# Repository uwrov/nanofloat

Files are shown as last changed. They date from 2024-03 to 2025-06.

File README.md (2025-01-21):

# NanoFloat

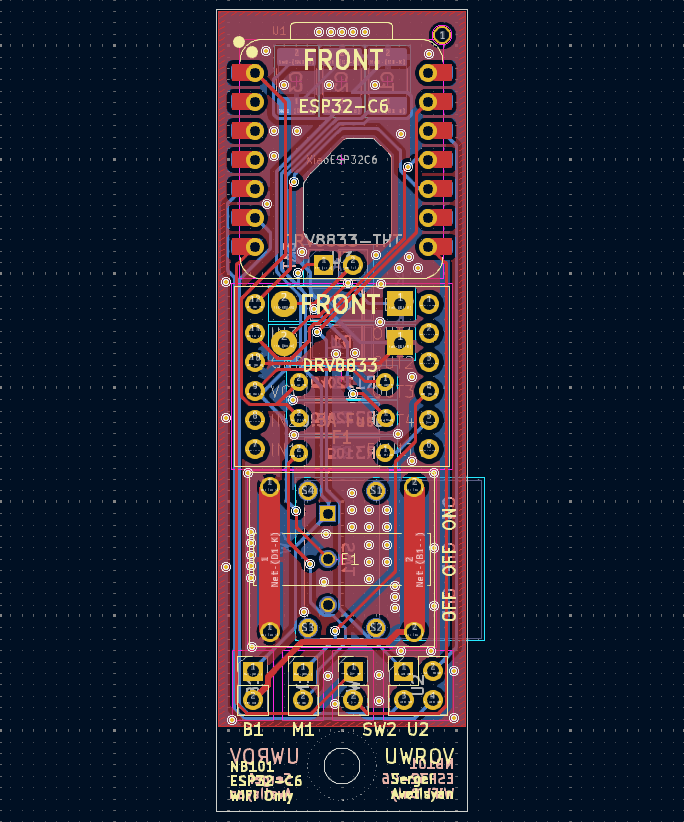
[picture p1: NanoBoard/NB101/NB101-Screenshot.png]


# Helpful Links:
>[Micropython Docs](https://docs.micropython.org/en/latest/esp32/quickref.html)

>[WebREPL GitHub](https://github.com/micropython/webrepl)

>[Seeed Studio ESP32C6 (Latest Version) Pinout](https://wiki.seeedstudio.com/xiao_esp32c6_getting_started/)

>[Seeed Studio ESP32C3 Pinout](https://wiki.seeedstudio.com/xiao_esp32c6_getting_started/)

>[DRV-8833 Motor Driver Pinout and User Guide](https://lastminuteengineers.com/drv8833-arduino-tutorial/)

>[Blue Robotics Pressure Sensor](https://bluerobotics.com/store/sensors-cameras/sensors/bar02-sensor-r1-rp/)

>[Flashing Micropython Firmware Reference Guide](https://docs.micropython.org/en/latest/esp32/tutorial/intro.html#esp32-intro)

>[MS583730BA01-50 Pressure Sensor Datasheet](https://www.te.com/usa-en/product-MS583730BA01-50.datasheet.pdf)

>[MS5837 Official Python Library](https://github.com/bluerobotics/ms5837-python)

>[Standalone Pressure Sensor DigiKey Page](https://www.digikey.com/en/products/detail/te-connectivity-measurement-specialties/MS583730BA01-50/5629501)

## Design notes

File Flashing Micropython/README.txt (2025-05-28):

ESP32C3:

1. Hold down B or Boot button and connect the board to your PC using a data USB-C cable (this will put it in bootloader mode).

2. Open CMD

3. devmgmt.msc and check COM port

4. esptool --port COM_ erase_flash

5. If you cloned the repo, cd to this directory of the directory where you downloaded your flash binary

6. esptool --port COM_ write_flash -z 0x0 ESP32C6-MicroPython.bin

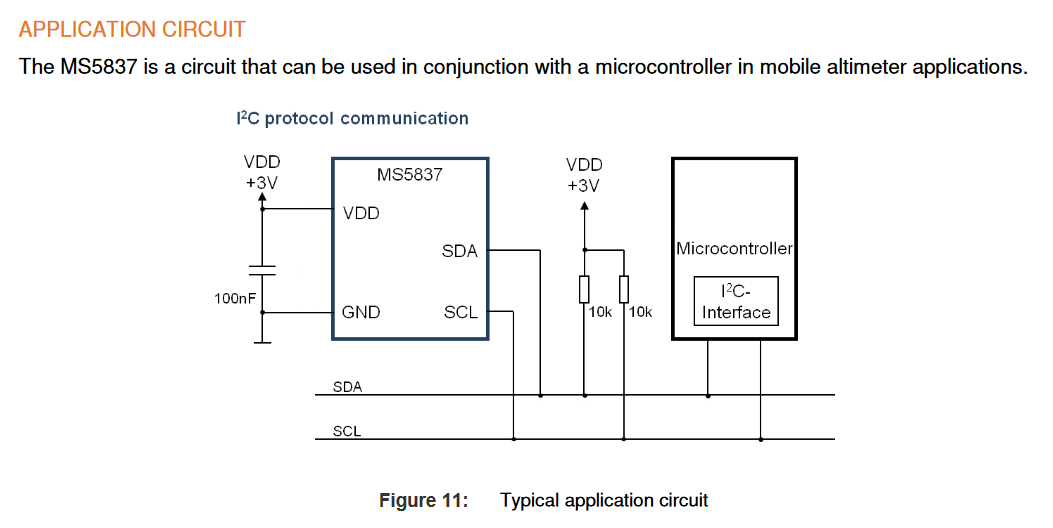
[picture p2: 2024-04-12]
Schematic-Image.png

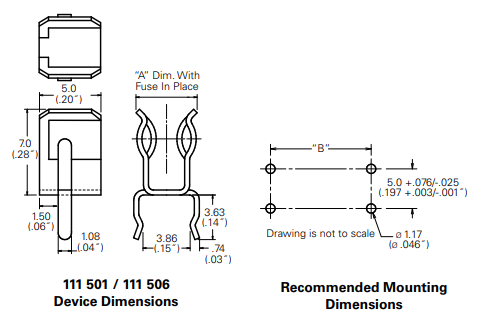
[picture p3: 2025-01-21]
FuseHolderDimensions.png

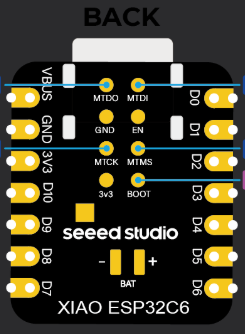
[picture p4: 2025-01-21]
ESP32C6-Reference-Backside.png

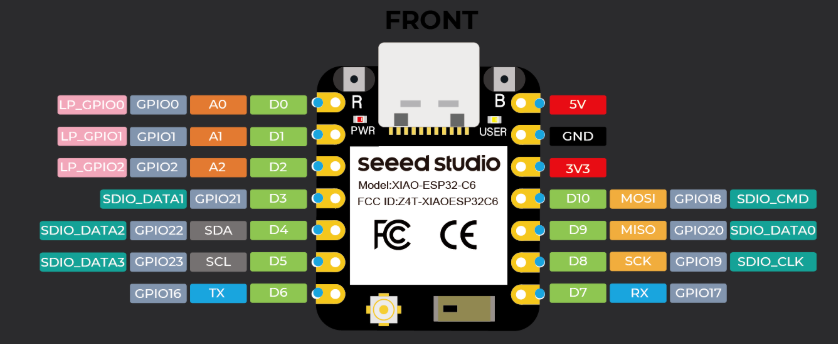
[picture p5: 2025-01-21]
ESP32C6-Reference.png

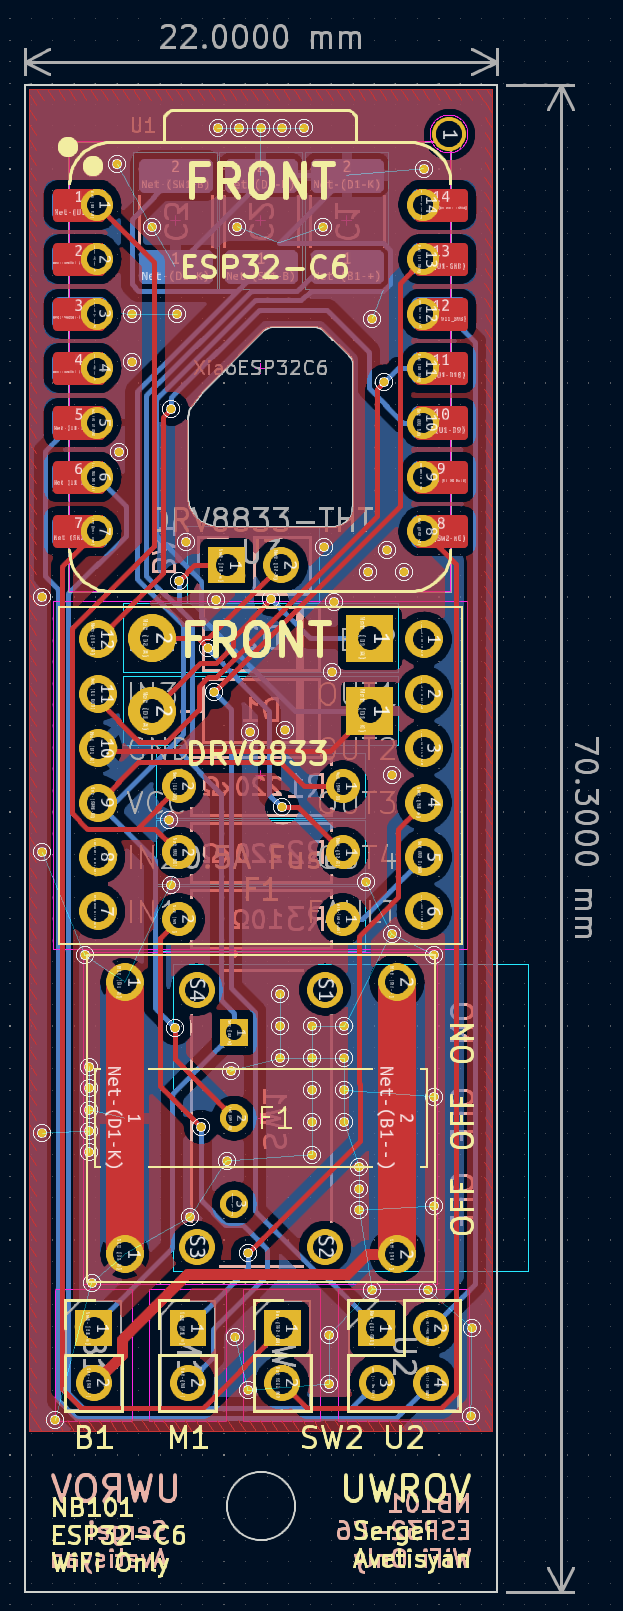
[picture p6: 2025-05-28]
NanoBoard/NB101/NB101.png

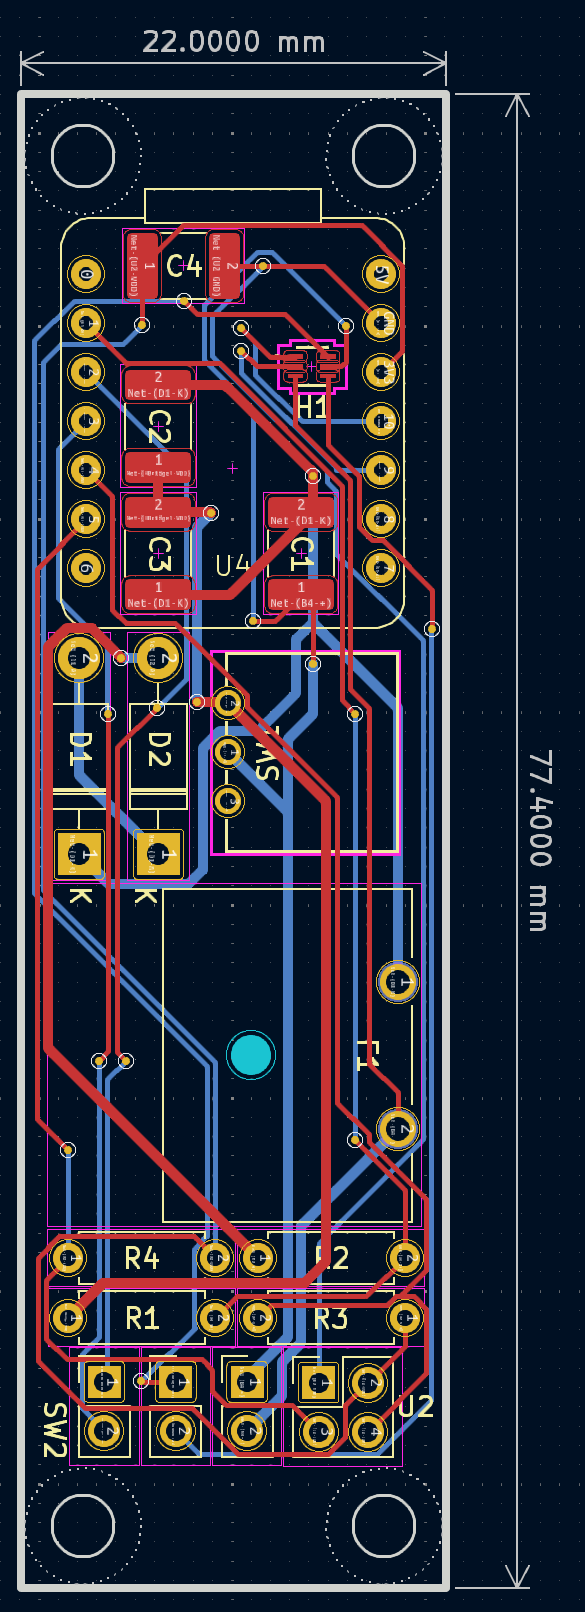
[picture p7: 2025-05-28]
NanoBoard/NB001/NB001.png

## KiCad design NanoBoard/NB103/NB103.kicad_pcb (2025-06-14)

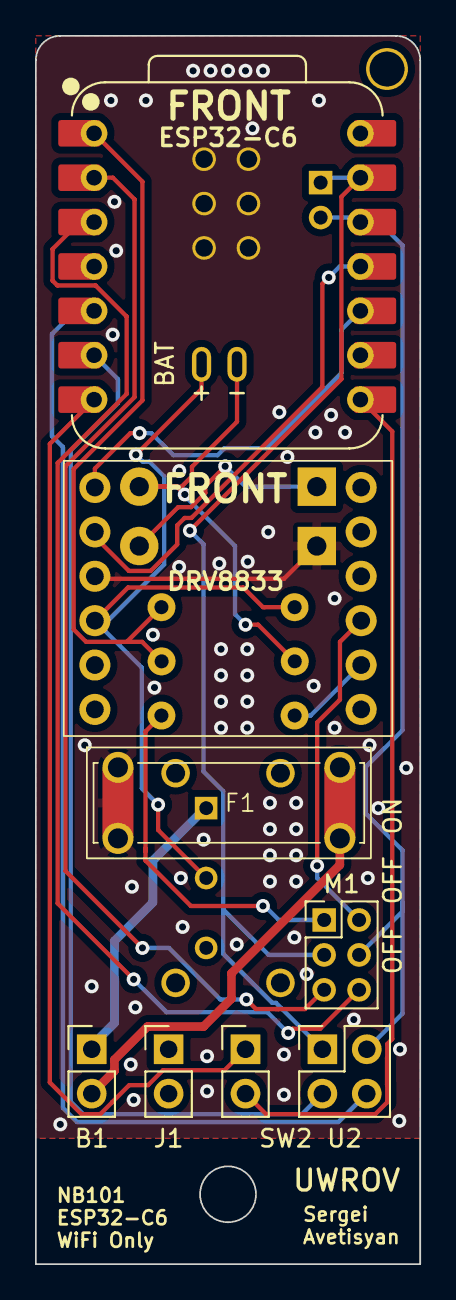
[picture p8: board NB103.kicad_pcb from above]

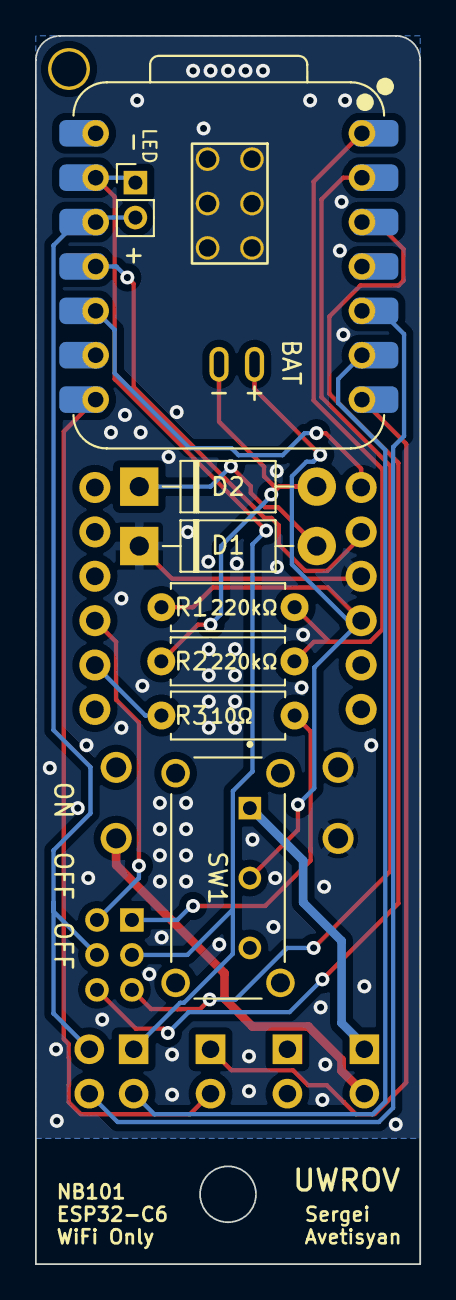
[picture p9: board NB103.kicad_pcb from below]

Board: 2 copper layers, 22.0 x 70.3 mm, 17 parts (8 on the bottom side), 18 nets.

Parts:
B1: 6V; PinHeader_1x02_P2.54mm_Vertical
BAT: PinHeader_1x02_P2.54mm_Vertical
D1, D2: Rectifier Diode; D_DO-41_SOD81_P10.16mm_Horizontal
F1: 0.5A Fuse; Fuse-Holder-01110501Z
J1: Motor_DC; PinHeader_1x02_P2.54mm_Vertical
LED: PinHeader_1x02_P2.00mm_Vertical
M1, M1#2: PinHeader_2x03_P2.00mm_Vertical
R1, R2: 220kOhm; R_Axial_DIN0207_L6.3mm_D2.5mm_P7.62mm_Horizontal
R3: 10 Ohm; R_Axial_DIN0207_L6.3mm_D2.5mm_P7.62mm_Horizontal
SW1: SW; Slide-Switch-EG1224
SW2: Limit Switch; PinHeader_1x02_P2.54mm_Vertical
U1: XiaoESP32C6; XIAO-ESP32C6-DIP
U2: MS583730BA01-50; PinHeader_2x02_P2.54mm_Vertical
U3: DRV8833-THT

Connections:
unnamed: B1.1 (+), SW1.1 (A)
unnamed: B1.2 (-), F1.2
unnamed: D1.2 (A), D2.1 (K)
unnamed: D1.1 (K), F1.1, U3.10 (GND)
unnamed: BAT.2, D2.2 (A), R2.1
unnamed: M1#2.2, U3.4 (Out3)
unnamed: M1#2.1, R3.2
unnamed: BAT.1, R1.1, SW1.2 (B), U3.9 (VCC)
unnamed: SW2.1 (COM), U1.7 (D6)
unnamed: SW2.2 (NC), U1.8 (D7)
unnamed: R1.2, R2.2, U1.1 (D0)
unnamed: U1.5 (D4_SDA), U2.4 (SDA)
unnamed: U1.6 (D5_SCL), U2.3 (SCL)
unnamed: U1.10 (D9), U3.12 (In4)
unnamed: U1.11 (D10), U3.11 (In3)
unnamed: LED.1, M1#2.3, U1.13 (GND), U2.1 (GND)
unnamed: LED.2, M1#2.4, U1.12 (VCC_3V3), U2.2 (VDD)
unnamed: R3.1, U3.5 (Out4)

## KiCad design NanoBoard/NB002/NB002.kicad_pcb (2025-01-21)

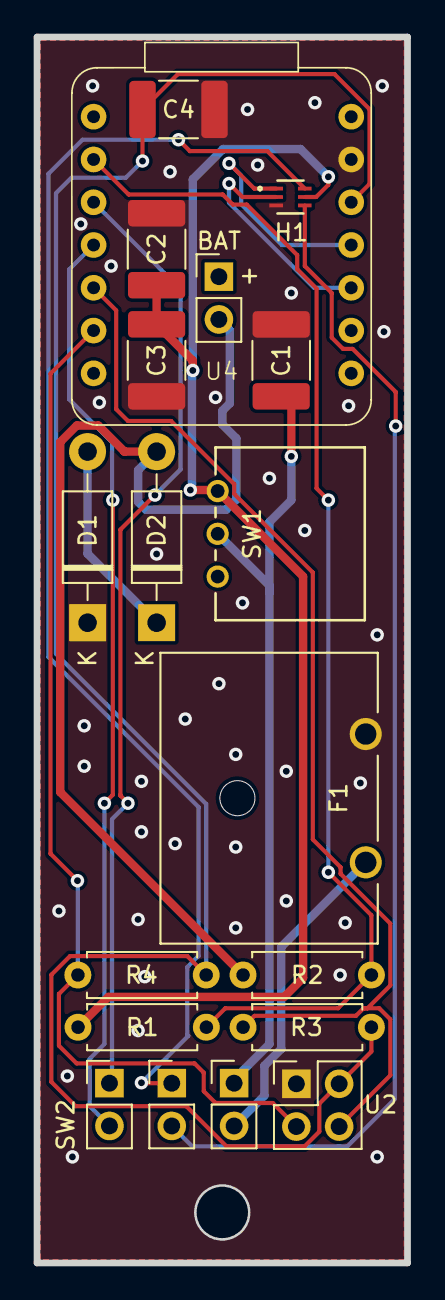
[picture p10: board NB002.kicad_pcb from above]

Board: 2 copper layers, 22.0 x 72.8 mm, 19 parts (0 on the bottom side), 13 nets.

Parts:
B4: 1.5V; PinHeader_1x02_P2.54mm_Vertical
BAT: PinHeader_1x02_P2.54mm_Vertical
C1, C2, C3, C4: C_Small; C_1812_4532Metric_Pad1.57x3.40mm_HandSolder
D1, D2: Rectifier Diode; D_DO-41_SOD81_P10.16mm_Horizontal
F1: 2A Fuse; FUSE_01530007Z
H1: DRV8220DRLR
M1: Motor_DC; PinHeader_1x02_P2.54mm_Vertical
R1, R2: 220kOhm; R_Axial_DIN0207_L6.3mm_D2.5mm_P7.62mm_Horizontal
R3, R4: 10kOhm; R_Axial_DIN0207_L6.3mm_D2.5mm_P7.62mm_Horizontal
SW1: SW; SW_09.10290.01_EAO
SW2: Limit Switch; PinHeader_1x02_P2.54mm_Vertical
U2: MS583730BA01-50; PinHeader_2x02_P2.54mm_Vertical
U4: XiaoESP32C3; XIAO_ESP32C3_THT

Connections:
unnamed: B4.1 (+), C1.1, SW1.1 (A)
unnamed: B4.2 (-), F1.2
unnamed: D1.2 (A), D2.1 (K)
unnamed: C1.2, C2.2, C3.1, C4.2, D1.1 (K), F1.1, H1.3, U2.1 (GND), U4.GND
unnamed: BAT.2, D2.2 (A), R2.1
unnamed: H1.1, U4.10 (D9)
unnamed: H1.6, M1.1 (+)
unnamed: H1.4, M1.2 (-)
unnamed: C2.1, C3.2, H1.5, R1.1, SW1.2 (B)
unnamed: R4.1, U2.3 (SCL), U4.5 (D4_SDA)
unnamed: R3.2, U2.4 (SDA), U4.4 (D3)
unnamed: C4.1, R3.1, R4.2, U2.2 (VDD), U4.3V3
unnamed: R1.2, R2.2, U4.1 (D0)

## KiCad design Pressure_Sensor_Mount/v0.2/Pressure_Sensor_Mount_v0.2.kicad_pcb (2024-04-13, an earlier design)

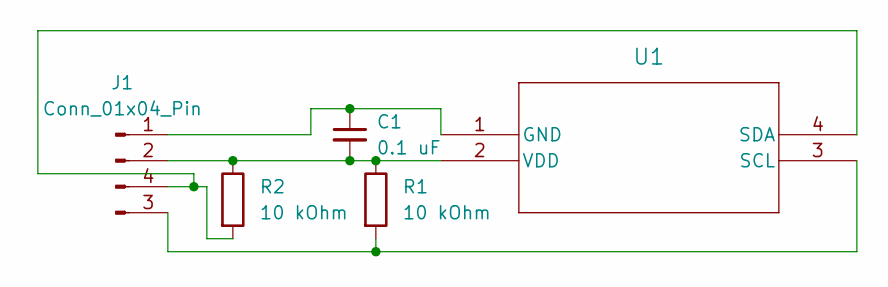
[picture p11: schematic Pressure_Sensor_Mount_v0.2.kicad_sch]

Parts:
C1: 0.1 uF; C_Disc_D3.0mm_W1.6mm_P2.50mm
J1: Conn_01x04_Pin; PinHeader_1x04_P2.54mm_Vertical
R1, R2: 10 kOhm; R_Axial_DIN0309_L9.0mm_D3.2mm_P12.70mm_Horizontal
U1: Pressure Sensor Footprint

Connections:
unnamed: C1.1, J1.1, U1.1 (GND)
unnamed: C1.2, J1.2, R1.1, R2.1, U1.2 (VDD)
unnamed: J1.3, R1.2, U1.3 (SCL)
unnamed: J1.4, R2.2, U1.4 (SDA)

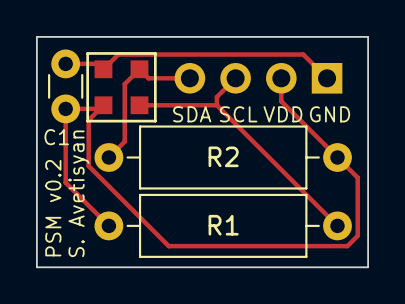
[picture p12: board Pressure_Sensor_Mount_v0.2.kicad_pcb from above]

Board: 2 copper layers, 18.4 x 12.8 mm, 5 parts (1 on the bottom side), 4 nets.

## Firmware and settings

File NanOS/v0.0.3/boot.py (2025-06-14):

#================================================================================================================================================
#                                                              imports

# This file is executed on every boot (including wake-boot from deepsleep)
# It includes the entire code for the nanofloat, all functions are defined here

# Importing sleep to allow for waiting
from time import sleep, sleep_ms

# Importing Piston Position
# Reference save_position function to see how the position is updated.
import piston_pos
position = piston_pos.position

# Impoting sys, it is used in the sys.exit() function within endFunc()
import sys

# Importing the WiFi config files, which store the network name, or SSID, and the password
import wlan_cfg

# Importing the i2c library for our pressure sensor
#import ms5837

# Importing the following from the esp32's operating system:
#       - Pin to control GPIOs
#       - I2C to control sensors operating over the i2c serial bus
from machine import Pin, I2C, ADC

# Importing WebREPL to interface wirelessly with the controller's WiFi Access Point 
import webrepl

# Importing network which will allow the controller to start up its own WiFi Access Point
import network 

# Starting up the WiFi Access Point. In this case, the network is set to AP_IF, putting it into access point mode.
# In other use cases, the network may be set to STA_IF which sets it as a default station which can connect to WiFi.
try:
    ap = network.WLAN(network.STA_IF)
    ap.config(beep)
    print("Startup in Station Mode")
except:
    print("---")
    print("WARNING: ROUTER CONNECTION FAILED: Initializing Access-Point Mode")
    print("---")
    try:
        ap = network.WLAN(network.AP_IF)
        ap.config(ssid = wlan_cfg.network_name, max_clients = 1)
        ap.active(True)
        print("Startup in Access-Point Mode Successful")
    except:
        print("Startup in Access-Point Mode Failed, USB Connection Required")

# Starting up WebREPL access, which sets the password for access and assigns the default IP address to the controller
# Reset the psasword to what you prefer by changing it in the webrepl_cfg.py file, default is "123"
webrepl.start()

# Defining the GPIOs (digital pin numbers do not always align with true GPIO numbers, check Seeed Studio XIAO ESP32C3 datasheet)
d1 = Pin(1, Pin.IN) #------------------ Encoder A phase
d2 = Pin(2, Pin.IN) #------------------ Encoder B phase
d3 = Pin(21, Pin.OUT) #---------------- UNUSED
d4 = Pin(22) #------------------------- I2C bus SDA
d5 = Pin(23) #------------------------- I2C bus SCL
d6 = Pin(16, Pin.IN, Pin.PULL_DOWN) #-- Limit Switch input pin
d7 = Pin(17, Pin.OUT) #---------------- Limit Switch Pullup pin (Enable/Disable limit switch)
d8 = Pin(19, Pin.OUT) #---------------- UNUSED
d9 = Pin(20, Pin.OUT) #---------------- Motor Input 1
d10 = Pin(18, Pin.OUT) #--------------- Motor Input 2

# Defining the encoder read pins
en_A = d1
en_B = d2

# Defining the pins for the I2C bus and creating the i2c object
sda = d4
scl = d5
i2c = I2C(scl=scl, sda=sda)

# Defining the Limit Switch Pins and setting the limit switch activator pin to be pulled high, or enabled.
lim_sw_state = d6
lim_sw_activate = d7
lim_sw_activate.value(1)

# Defining the Motor Input Pins
motor1 = d9
motor2 = d10

#================================================================================================================================================
#                                                           piston_out

def piston_out():
    motor1.value(1)
    motor2.value(0)

#================================================================================================================================================
#                                                           piston_in

def piston_in():
    motor1.value(0)
    motor2.value(1)

#================================================================================================================================================
#                                                           piston_stop

def piston_stop():
    motor1.value(0)
    motor2.value(0)

#================================================================================================================================================
#                                                           save_position

def save_position():
    
    global position
    
    with open("piston_pos.py", "w") as f:

        f.write('position = %d' % (position))
        
        f.close()
        
#================================================================================================================================================
#                                                           position_reset

def position_reset():
    
    global position
    
    position = 0
    
    save_position()

#================================================================================================================================================
#                                                           piston_move

# piston_move() requires three arguments: method, target, and units (optional, raw counts assumed).
#
# method: a string which decides whether the piston should move an arbitrary delta_x or if it should move to a specified position.
# |
# '--> accepts: "rel" or "relative"
#               "abs" or "absolute"
#
# target: a float representing either the relative distance the piston should move or the absolute position to which it should move.
# |
# '--> accepts: for relative values, either positive or negative floats for retraction and extension respectively
#               for absolute values, only positive floats
#
# units: a string which defines the units of the target argument. If left unspecified, raw counts are used. (WORK IN PROGRESS, CURRENTLY SUPPRESSED)
# |
# '--> accepts: "cm" (centimeters)
#               "mm" (millimeters)
#               "revs_o" (revolutions of output shaft)
#               "revs_i" (revolutions of input shaft)

# A-Channel previous state tracker initialization
a_prev = 0

delta = 0

# Encoder ISR to run as the handler for the interrupt and update position
def encoder_isr(pin):
    global delta, a_prev
    a = en_A.value()
    if a != a_prev:
        delta += 1

# Initializing interrupt to watch the encoder outputs
en_A.irq(trigger=Pin.IRQ_RISING, handler=encoder_isr)

target_pos = position
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

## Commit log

2024-03-08 Prototype Pressure Sensor Mounting PCB
    [nanofloat-pressure-sensor-mount.kicad_pcb]
2024-03-08 uploading NanOS v0.0.1
    v0.0.1, as demonstrated on 3/3/2024. The first functional prototype of NanOS.
2024-03-08 uploaded NanOS v0.0.1
    NanOS v0.0.1 as demonstrated on 3/3/24. The first functional prototype, many features missing but main structure is defined.
    [boot.py]
2024-03-11 Updating KiCAD project files
    [nanofloat-pressure-sensor-mount.kicad_pcb, nanofloat-pressure-sensor-mount.kicad_sch]
2024-03-11 Updated gitignore for KiCAD PCBs
2024-03-11 Added Silkscreen Text to PCB
    [Pressure_Sensor_Mount.kicad_pcb, Pressure_Sensor_Mount.kicad_sch, nanofloat-pressure-sensor-mount.kicad_pcb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]
2024-03-11 Fixed Silkscreen Error
    [Pressure_Sensor_Mount.kicad_pcb]
2024-03-11 Manufacturing Changes
    [Pressure_Sensor_Mount-B_Cu.gbl, Pressure_Sensor_Mount-B_Mask.gbs, Pressure_Sensor_Mount-B_Paste.gbp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]
2024-03-11 Updated Manufacturing Plots
    [Pressure_Sensor_Mount-B_Cu.gbl, Pressure_Sensor_Mount-B_Mask.gbs, Pressure_Sensor_Mount-B_Paste.gbp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]
2024-03-12 Zipped Gerber Files for Manufacturing
2024-03-13 Updating Wireless Settings for v0.0.2
2024-03-13 Improving Wireless Configuration for v0.0.2
2024-03-28 Uploaded pressure sensor official i2c library
2024-03-28 Updating boot.py with i2c library
2024-03-31 Initial Full Float Schematic
    [Nano-Float_Schematic.kicad_pcb, Nano-Float_Schematic.kicad_sch]
2024-03-31 Update a label and add lock files to gitignore
    [Nano-Float_Schematic.kicad_sch]
2024-03-31 Updated Battery Circuit to implement the fuse correctly and added to-do list
    [Nano-Float_Schematic.kicad_sch]
2024-04-02 Updated with global labels
    [Nano-Float_Schematic.kicad_sch]
2024-04-11 Modified boot.py and KiCad Schematic
    [Pressure_Sensor_Mount.kicad_sch]
2024-04-12 Uploaded new pressure sensor mount schematic and PCB
    [Pressure_Sensor_Mount_v0.1.kicad_pcb, Pressure_Sensor_Mount_v0.1.kicad_sch, Pressure_Sensor_Mount_v0.2.kicad_pcb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]
2024-04-13 Updated PSM v0.2
    [Pressure_Sensor_Mount_v0.2.kicad_pcb]
2024-04-14 Got the Footprints! Need to play around more with the orientation of everything on the final PCB
    [ESE-22MV21T.step, Nano-Float_Schematic.kicad_pcb, Nano-Float_Schematic.kicad_sch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]
2024-04-18 updated float schematic
    [Nano-Float_Schematic.kicad_sch]
2024-05-12 footprints? yes!
    [Nano-Float_Schematic.kicad_pcb, Nano-Float_Schematic.kicad_sch]
2024-05-26 SID -> PCB
    [FloatSID.kicad_sch]
2024-06-02 my float pcb work
    [FloatSID.kicad_pcb, FloatSID.kicad_sch]
2024-06-02 moving stuff around
    just making folders and such
    [FloatSID.kicad_pcb, FloatSID.kicad_sch]
2024-06-02 Float PCB Updates
    [FloatSID.kicad_pcb, FloatSID.kicad_sch, PSM-v0.3.kicad_pcb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]
2024-06-02 renamed folder
    [FloatSID.kicad_pcb, FloatSID.kicad_sch]
2024-06-10 Added Preliminary Traces for PCB
    [FloatSID.kicad_pcb]
2024-06-11 Updated PCB
    [FloatSID.kicad_pcb]
2024-06-11 Updated PCB and added Manufacturing Files
    [FloatSID-B_Cu.gbl, FloatSID-B_Mask.gbs, FloatSID-B_Paste.gbp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]
2024-06-11 Restructuring the Directories and Naming Conventions
    [ESE-22MV21T.step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]
2024-06-11 NB002 with Ground Plane and Mounting Edits
    [NB001-B_Cu.gbl, NB001-B_Mask.gbs, NB001-B_Paste.gbp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]
2024-06-12 Updated Ground Planes
    [NB002.kicad_pcb]
2024-06-12 Added NGP PCB
    [NB001-B_Cu.gbl, NB001-B_Mask.gbs, NB001-B_Silkscreen.gbo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]
2025-01-21 Full Rework of NanoBoard Libraries, Updated Final Version of NB101
    [ESE-22MV21T.step, FloatSID.kicad_sch, NB002.kicad_pcb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]
2025-05-28 Updates to boards and Flashing Micropython
    [NB102.kicad_pcb, NB102.kicad_sch]
2025-06-14 Introduced NanOS v0.0.3 with Encoder Support
    [NB103.kicad_pcb, NB103.kicad_sch]
